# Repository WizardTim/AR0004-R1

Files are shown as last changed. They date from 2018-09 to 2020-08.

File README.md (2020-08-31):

# AR0004-R1
PCB design files for 10W D50/D65 (5000K/6500K ANSI approximate) standard illuminant modular LED panels. Note any 3528 PLCC LED will suffice provided forward voltage and maximum current are accounted for.

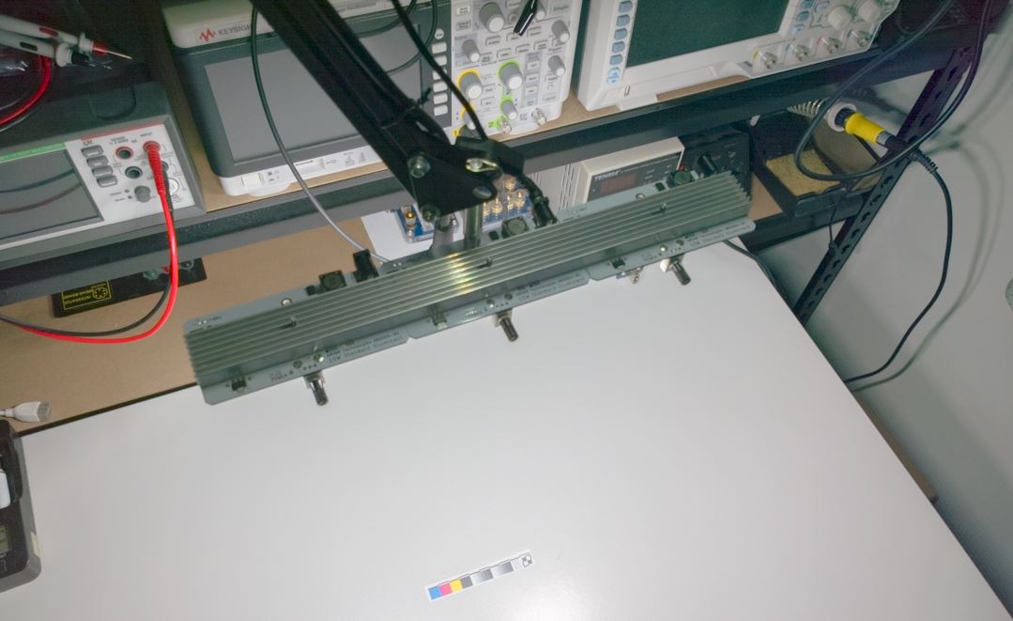
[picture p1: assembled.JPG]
Assembled Device


### Design Notes:
* Potentiometer mounts on LED side of PCB, reverse pins and deadzone resistor in schematic for opposite mounting
* Thermal design of PCB heatsinking for LEDs is insufficient to cool LEDs to a temperature to prolong life, external heatsink & active cooling required for operation at 10W.
* A diffusor is recommended to reduce intensity of reflections and ease eye strain. Folded printer paper can suffice but will reduce efficiency and minorly affect colour point/spectral content.

### Related Videos
* _**'SMT Design Mistakes'**_: [https://youtu.be/_iIPJBWDUq0](https://youtu.be/_iIPJBWDUq0) discusses heat conduction problems related to interrupted copper areas on a typical 1 oz FR-4 PCB.

SMT Design Mistakes (https://youtu.be/_iIPJBWDUq0 "SMT Design Mistakes")

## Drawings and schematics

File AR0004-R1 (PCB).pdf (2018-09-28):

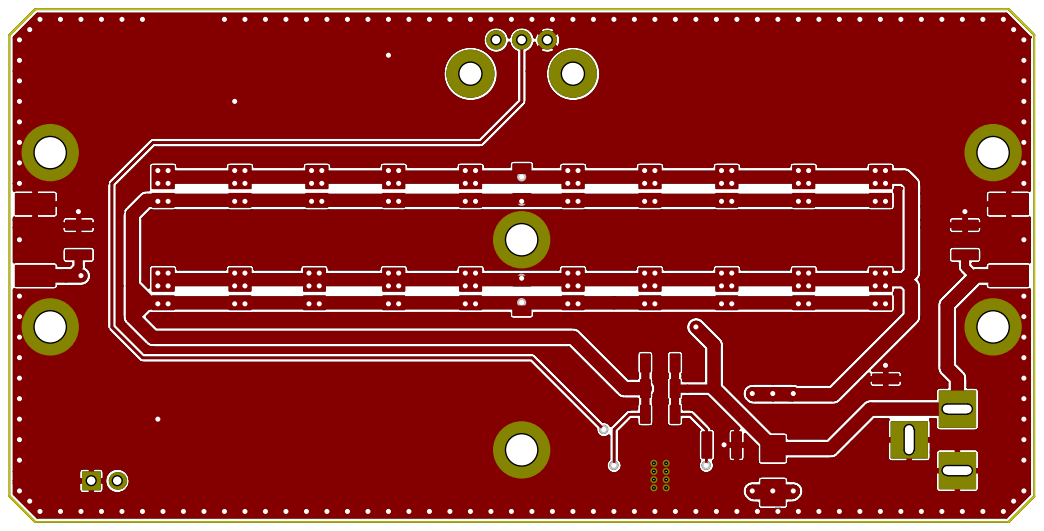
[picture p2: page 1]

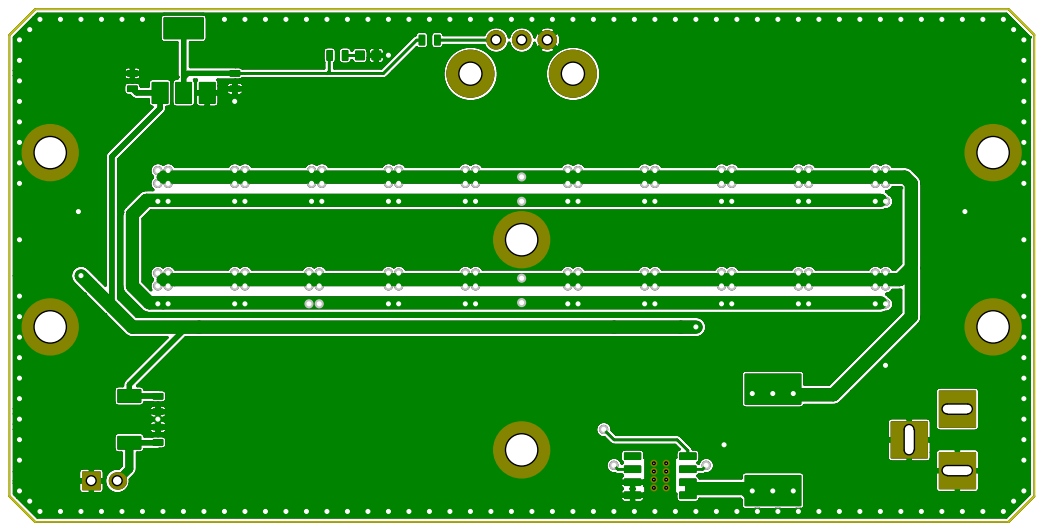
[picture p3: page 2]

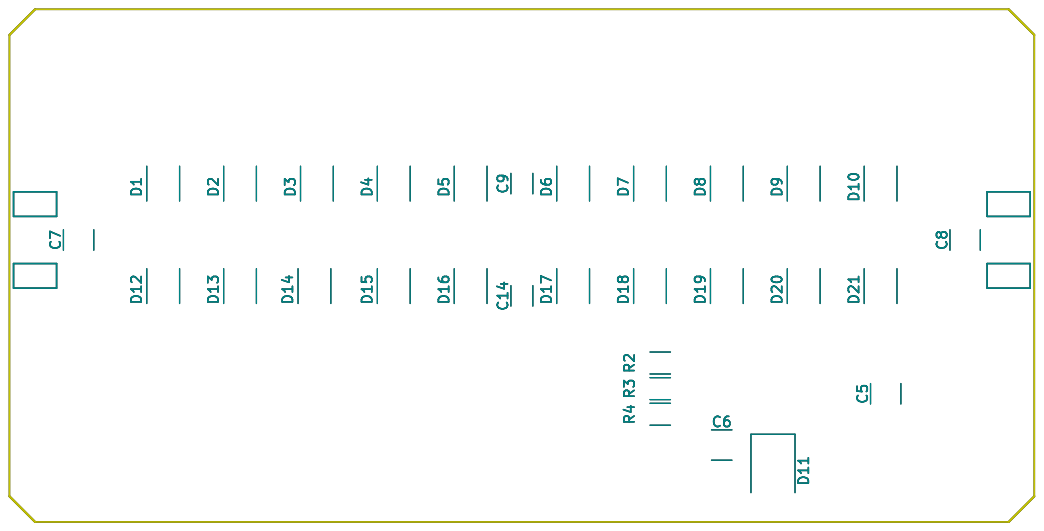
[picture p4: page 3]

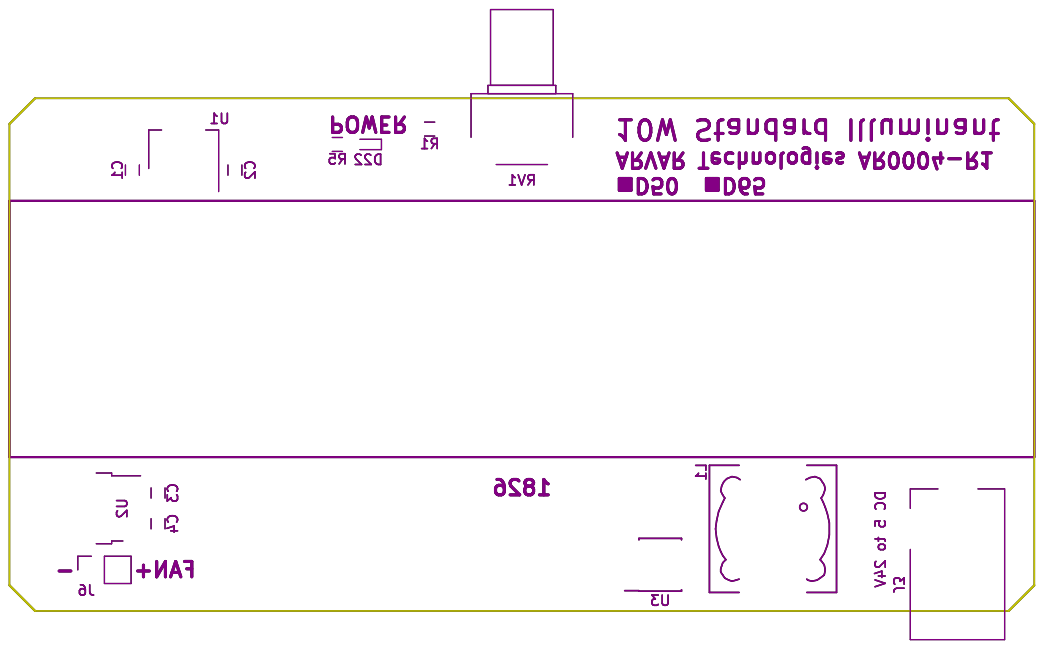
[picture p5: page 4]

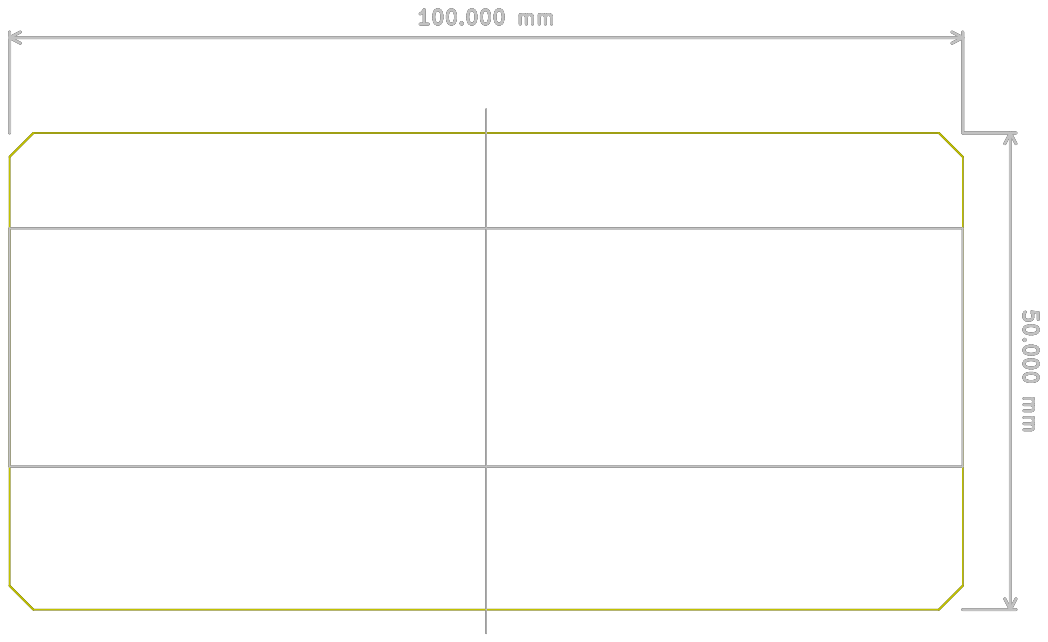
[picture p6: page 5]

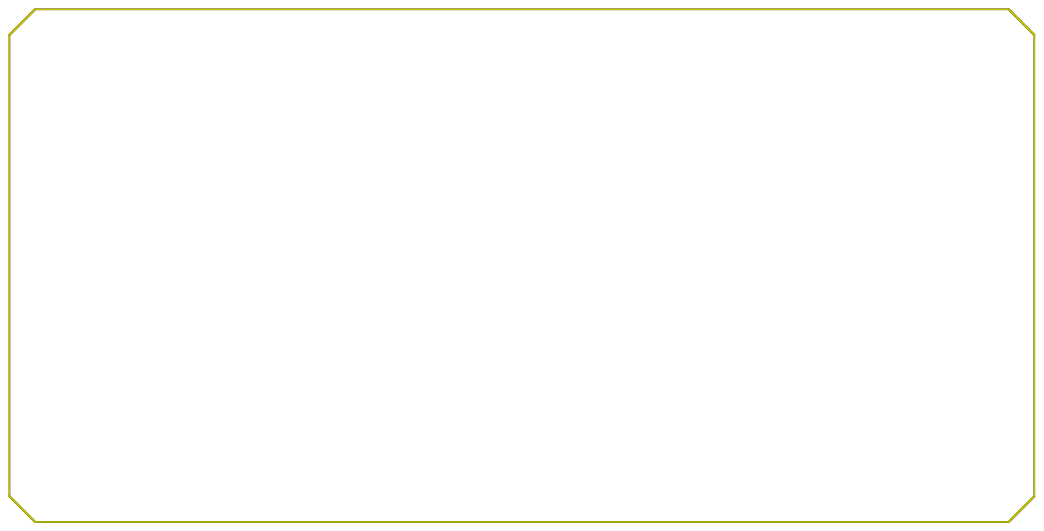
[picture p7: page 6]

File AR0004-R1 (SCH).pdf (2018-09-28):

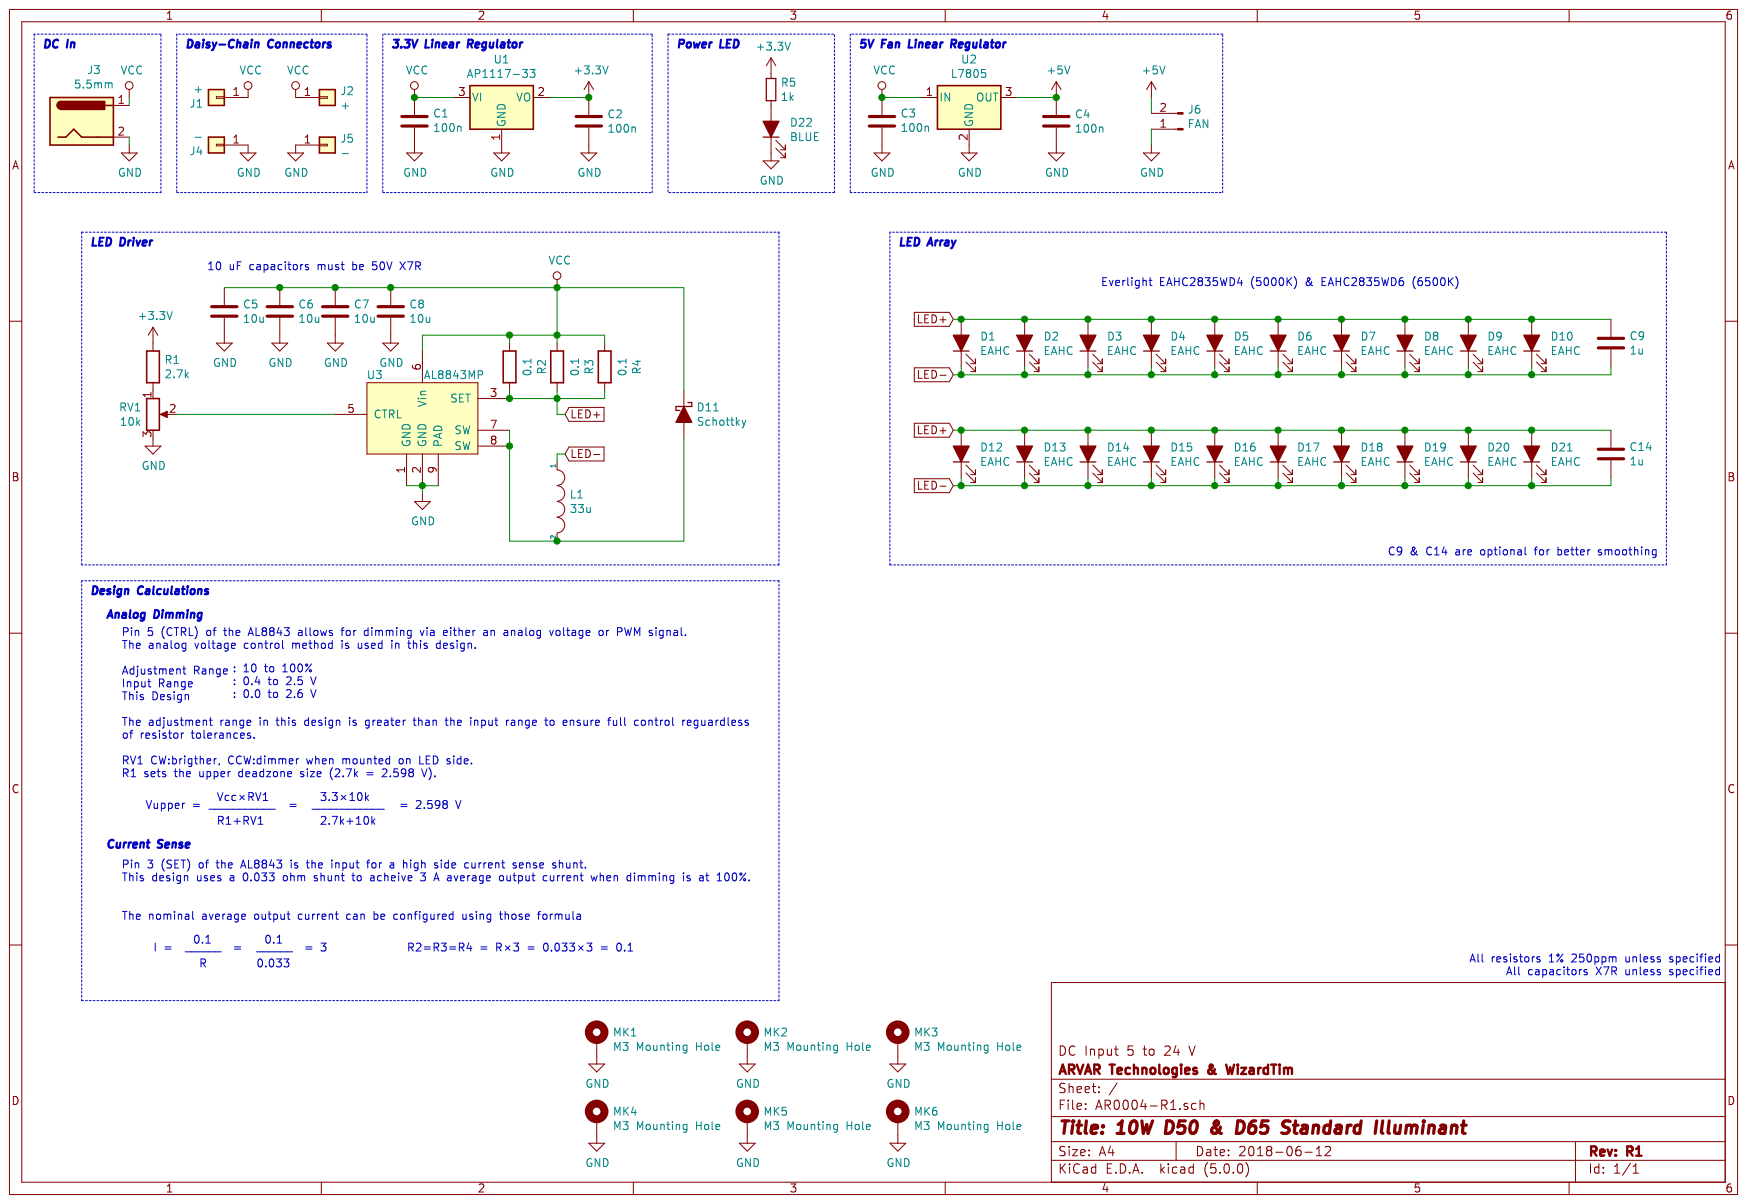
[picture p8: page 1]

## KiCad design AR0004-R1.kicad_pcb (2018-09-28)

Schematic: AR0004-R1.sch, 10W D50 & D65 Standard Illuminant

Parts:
C1, C2, C3, C4: 100n; R_0603
C5, C6, C7, C8: 10u; R_1210
C9, C14: 1u; R_1206
D1, D2, D3, D4, D5, D6, D7, D8, D9, D10, D12, D13, D14, D15, D16, D17, D18, D19, D20, D21: EAHC; LED_PLCC_2835
D11: Schottky; D_SMB
D22: BLUE; LED_0603
J1, J2: +; Test_Point_Keystone_5019_Minature
J3: 5.5mm; BARREL_JACK
J4, J5: -; Test_Point_Keystone_5019_Minature
J6: FAN; Pin_Header_Straight_1x02_Pitch2.54mm
L1: 33u; Choke_SMD_12x12mm_h4.5mm
MK1, MK2, MK3, MK4, MK5, MK6: M3 Mounting Hole; MountingHole_3.2mm_M3_ISO14580_Pad
R1: 2.7k; R_0603
R2, R3, R4: 0.1; R_1206
R5: 1k; R_0603
RV1: 10k; Potentiometer_Alps_RK09K_Vertical
U1: AP1117-33; SOT-223-3_TabPin2
U2: L7805; TO-252-2
U3: AL8843MP; HTSOP-8-1EP_3.9x4.9mm_Pitch1.27mm_ThermalVias_LargeCopper

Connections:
+3V3: C2.1, R1.1, R5.1, U1.2 (VO)
+5V: C4.1, J6.2, U2.3
GND: C1.1, C2.2, C3.1, C4.2, C5.2, C6.2, C7.2, C8.2, D22.1, J3.2, J3.3, J4.1, J5.1, J6.1, MK1.1, MK2.1, MK3.1, MK4.1, MK5.1, MK6.1, RV1.3, U1.1 (GND), U2.2, U3.1, U3.2, U3.9
LED+: C9.1, C14.1, D1.2, D2.2, D3.2, D4.2, D5.2, D6.2, D7.2, D8.2, D9.2, D10.2, D12.2, D13.2, D14.2, D15.2, D16.2, D17.2, D18.2, D19.2, D20.2, D21.2, R2.1, R3.1, R4.1, U3.3
LED-: C9.2, C14.2, D1.1, D2.1, D3.1, D4.1, D5.1, D6.1, D7.1, D8.1, D9.1, D10.1, D12.1, D13.1, D14.1, D15.1, D16.1, D17.1, D18.1, D19.1, D20.1, D21.1, L1.1
unnamed: D11.2, L1.2, U3.7, U3.8
unnamed: D22.2, R5.2
unnamed: R1.2, RV1.1
unnamed: RV1.2, U3.5
VCC: C1.2, C3.2, C5.1, C6.1, C7.1, C8.1, D11.1, J1.1, J2.1, J3.1, R2.2, R3.2, R4.2, U1.3 (VI), U2.1, U3.6

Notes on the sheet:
DC In
Daisy-Chain Connectors
3.3V Linear Regulator
5V Fan Linear Regulator
Power LED
LED Driver
LED Array
Current Sense
I =
0.1
______
Analog Dimming
C9 & C14 are optional for better smoothing
Everlight EAHC2835WD4 (5000K) & EAHC2835WD6 (6500K)
Design Calculations
Pin 5 (CTRL) of the AL8843 allows for dimming via either an analog voltage or PWM signal. The analog voltage control method is used in this design. Adjustment Range Input Range This Design The adjustment range in this design is greater than the input range to ensure full control reguardless of resi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
: 10 to 100% : 0.4 to 2.5 V : 0.0 to 2.6 V
10 uF capacitors must be 50V X7R
Pin 3 (SET) of the AL8843 is the input for a high side current sense shunt. This design uses a 0.033 ohm shunt to acheive 3 A average output current when dimming is at 100%. The nominal average output current can be configured using those formula
R2=R3=R4 = R×3 = 0.033×3 = 0.1
Vupper =
Vcc×RV1
___________
R1+RV1
3.3×10k
____________
2.7k+10k
= 2.598 V
0.033
= 3
All resistors 1% 250ppm unless specified All capacitors X7R unless specified

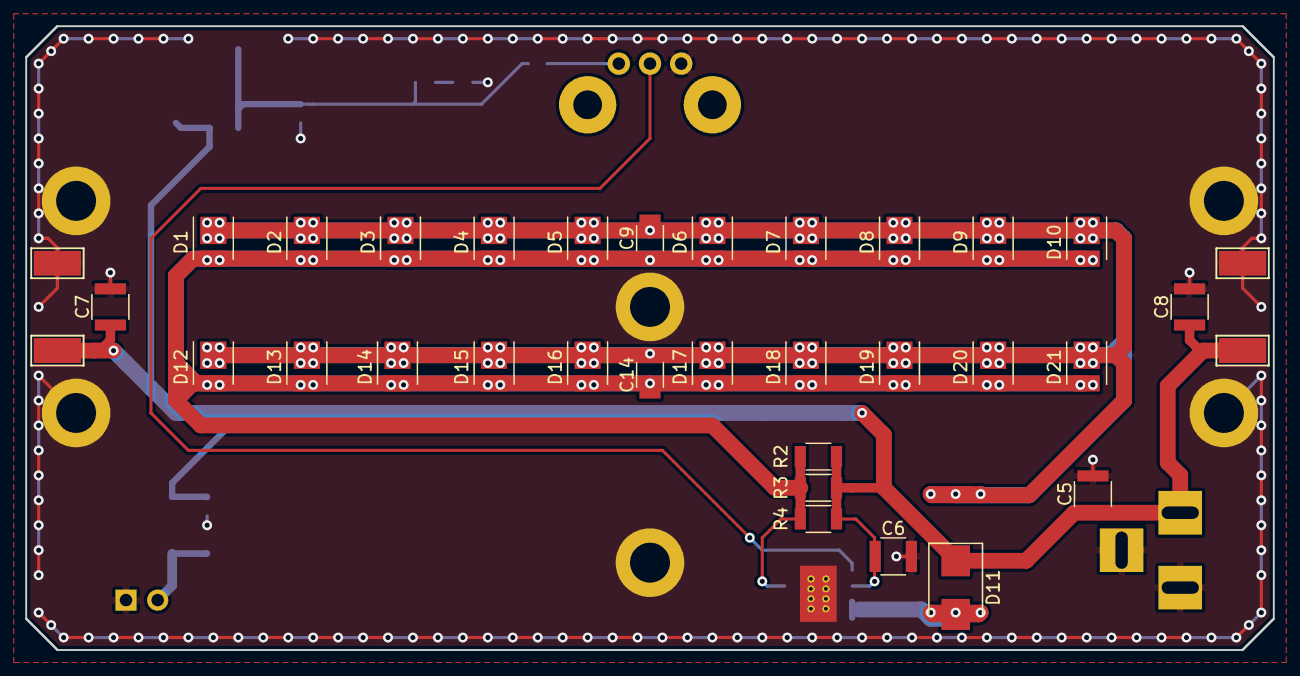
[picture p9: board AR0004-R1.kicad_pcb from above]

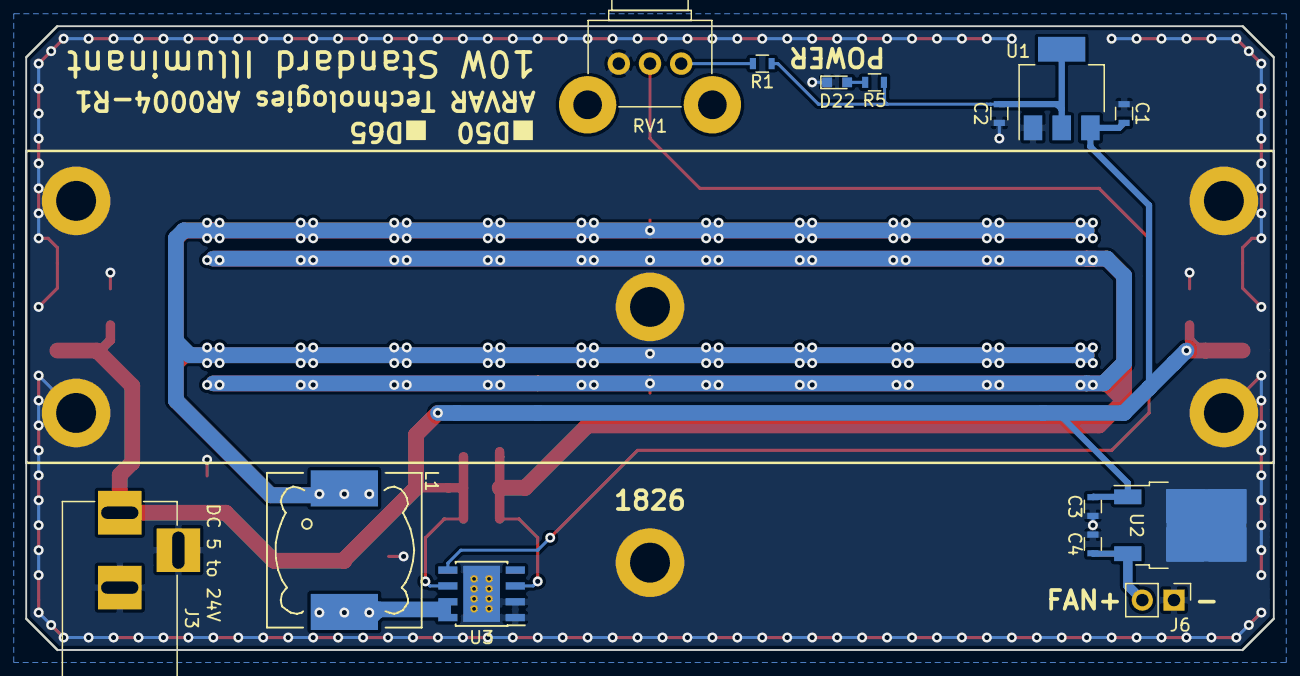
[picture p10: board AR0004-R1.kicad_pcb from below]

Board: 2 copper layers, 100.0 x 50.0 mm, 54 parts (14 on the bottom side), 10 nets.

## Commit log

2018-09-28 Uploaded project files
    [AR0004-R1.kicad_pcb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]
2020-08-31 Add image of assembled device
